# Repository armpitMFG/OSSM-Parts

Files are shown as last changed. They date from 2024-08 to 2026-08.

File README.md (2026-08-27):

# OSSM-Parts

### Summary 
- Parts designed/remixed for improving the OSSM experience
- Model assets (motors, PCBs, etc) to assist designing or rendering 
- Select OSSM Default parts for easier locating

### Print+Hardware Kits available on my Etsy - [https://armpitMFG.etsy.com](https://armpitMFG.etsy.com)

## Licensing

Open-source hardware under the
**[CERN Open Hardware Licence Version 2 - Strongly Reciprocal](LICENSE)**
(`CERN-OHL-S-2.0`), the same licence as the
[OSSM project](https://github.com/KinkyMakers/OSSM-hardware).

Some parts are derived from OSSM project source and carry both armpitMFG's and
the OSSM project's copyright. Some items are third-party work not covered by
this licence, notably `Model Assets` and `OSSM Tools/just_b Wrench`.

Per-part copyright and provenance: [NOTICE.md](NOTICE.md).

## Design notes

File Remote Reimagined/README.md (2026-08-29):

# OSSM Remote Reimagined
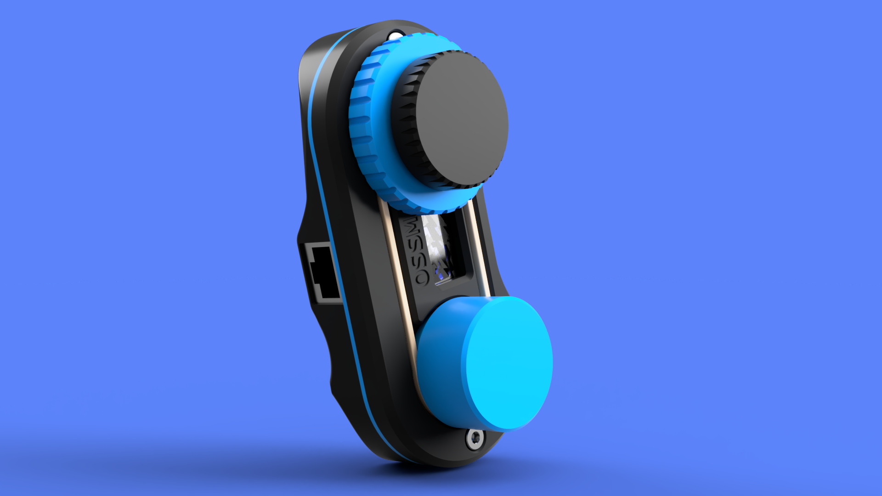
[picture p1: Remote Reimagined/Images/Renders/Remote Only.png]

360 Video (SFW)

## Summary    
Reimagines the OSSM Remote in single-handed form factor allowing control of Speed and Depth knobs (and click) with just one thumb.  
To be used in the right hand.

"Fail-safe" by still allowing traditional use of both knobs.

Print+Part kits: https://armpitmfg.etsy.com/listing/4295260669

### [Print Files](Files/)  

### [Demonstration Video (SFW)](https://www.youtube.com/watch?v=5V_SXpUnVo4) 

### Bill Of Materials
    2x M4-10mm
    ~80mm x ~4mm rubber band

### Notes:
 - Double check ***ALL*** support remnants are cleaned off the screen frame portion of the Board Interface before tightening down
     - Use caution/common-sense when placing the "Board Interface" on, if it feels like it's touching the screen component don't force it.  
Please message me and I will add additional clearance, I'm unsure the clearance needed to cover variance in boards but wanted to keep it tight-ish
 - I found that putting a single twist in the rubberband improves grip between the knobs.
 - There is room for improvement in filament usage and ergonomics for the Bottom, feel free to contribute designs!

### Updates:
  - 01.22.2025 - Added V1.1 Board Interface that gives more space. Untested print. [Images/V1.1.png](Images/V1.1.png)
  - 09.09.2024 - Increase pulley height by 1mm to increase reliability
  - 09.08.2024 - Add **Accent Stripe** file
  - 09.07.2024 - v1 released

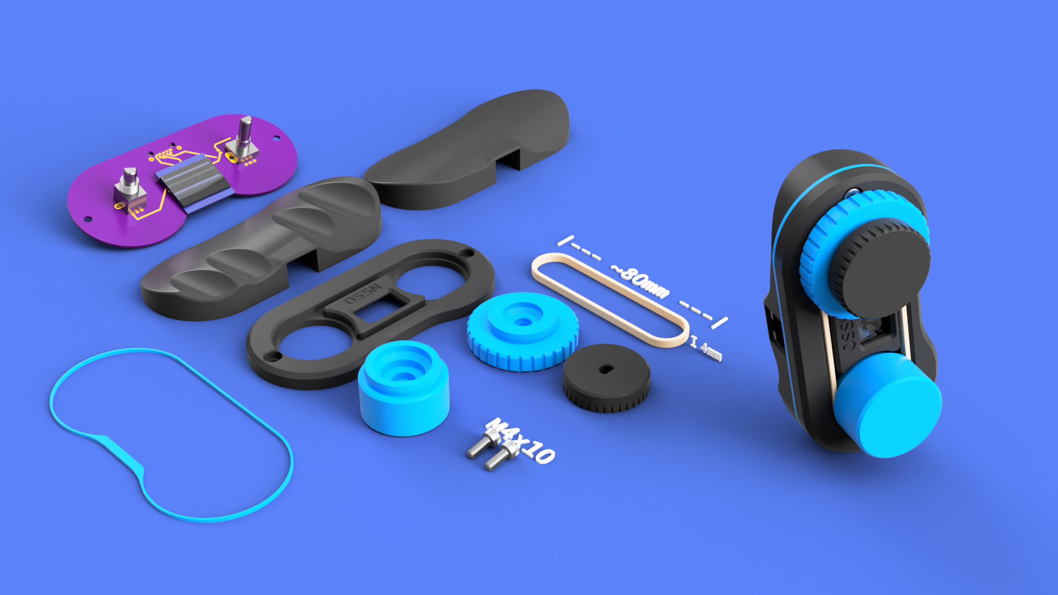
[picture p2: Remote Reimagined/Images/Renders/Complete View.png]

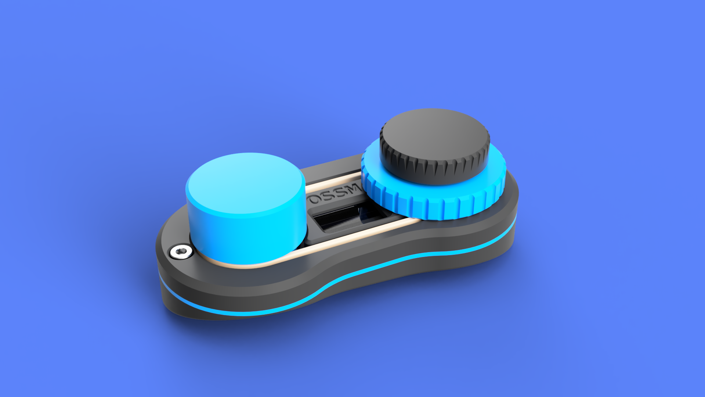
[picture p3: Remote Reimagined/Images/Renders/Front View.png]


## Printing:
  - 0.2mm layer height
  - Standard strength (5 wall) profile
  - 15% gyroid or crosshatch infill

Supports required for:
  - OSSM - Remote Reimagined - Board Interface.stl
  - OSSM - Remote Reimagined - Bottom (any).stl

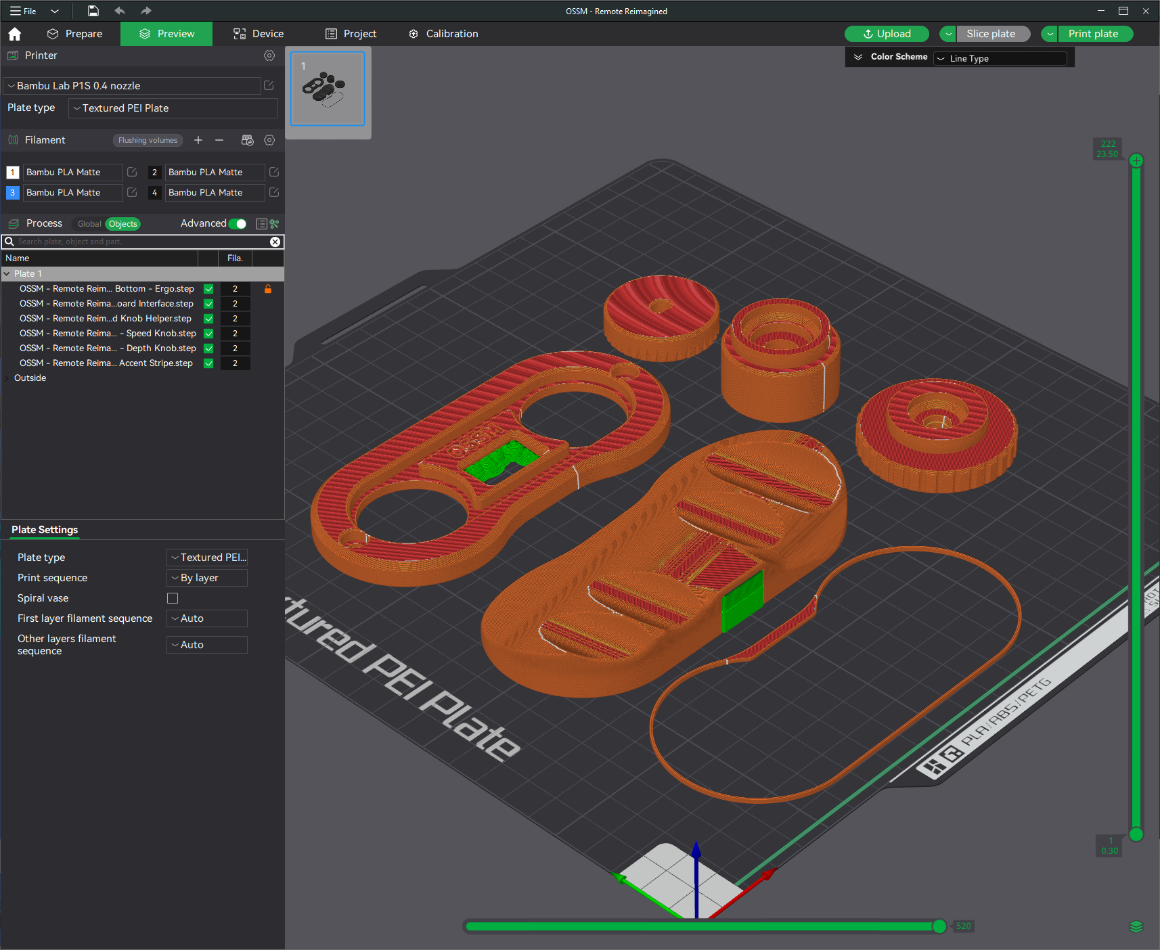
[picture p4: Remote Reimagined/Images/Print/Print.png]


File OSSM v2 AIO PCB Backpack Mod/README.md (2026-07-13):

# OSSM v2 All In One PCB Backpack Mod

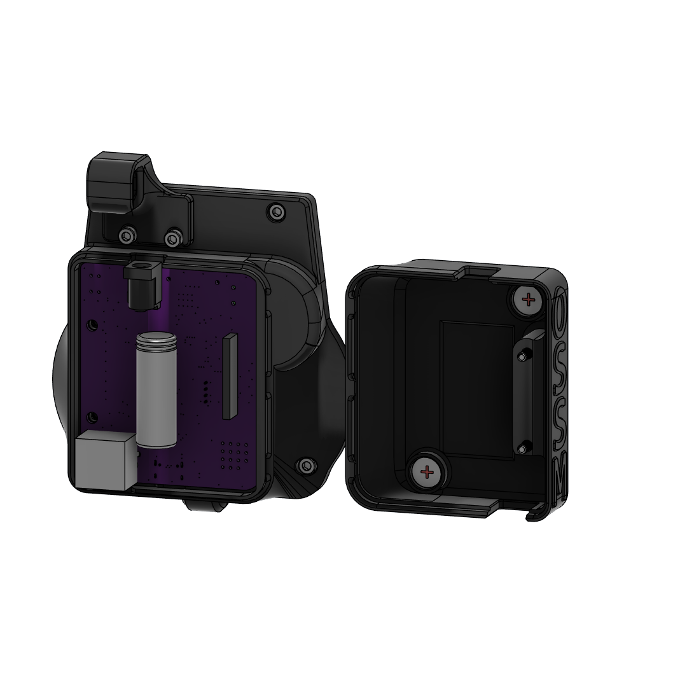
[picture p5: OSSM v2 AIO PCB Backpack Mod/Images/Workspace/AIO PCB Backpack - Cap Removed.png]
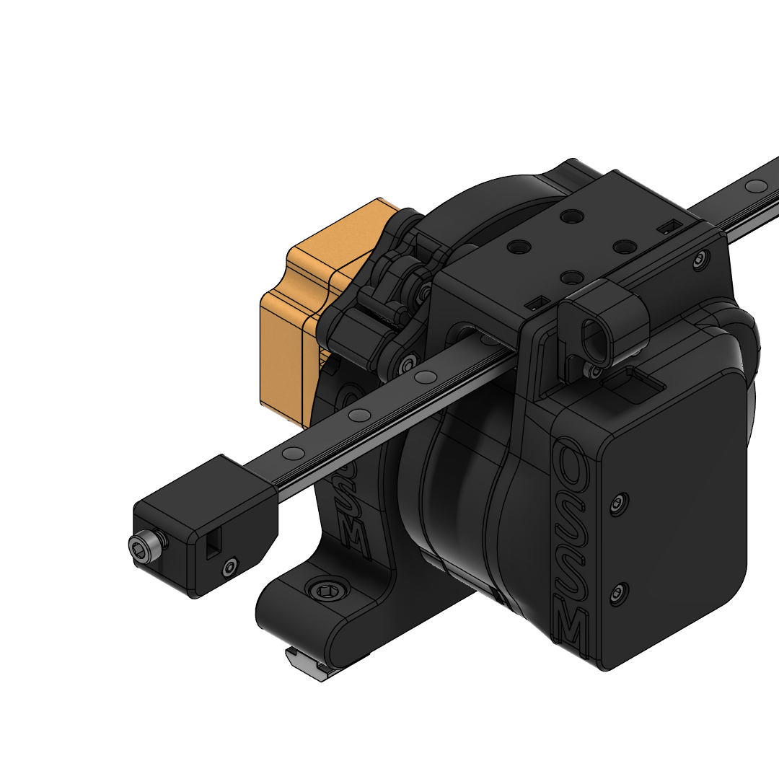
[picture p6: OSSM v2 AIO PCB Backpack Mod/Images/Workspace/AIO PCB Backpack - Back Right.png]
|||
| --- | --- |

## Summary   
This is a mod that converts the default "OSSM - Body - Cover" into a PCB enclosure with cable routing designed to pair up with my other mod - [OSSM Motor Cover](https://github.com/armpitMFG/OSSM-Parts/tree/main/OSSM%20Motor%20Cover) - on 57AIM30 "Gold Motor" setups.  

This OSSM setup utilizes the [PitClamp Mini](https://github.com/KinkyMakers/OSSM-hardware/tree/master/Printed%20Parts/Mounting/PitClamp%20Mini) mounting system.

Interlocking interface helps prevent fluid intrusion.

Print+Part kits: https://armpitmfg.etsy.com/listing/1861883228

### Requires v1.1 PitClamp Mini Motor Ring  

## Capacitor Support
- Supports capacitors up to 18mm diameter, should fit all existing v2.x reference boards

### Motor Support
- 57AIM30
- iHSV57
  - No cover mod for this motor, no passthru ring
  - Use 4pin header for motor signal

## [Print Files](Files/)  
 - All parts are intended to print in the provided file orientation (as seen in slicer preview below)  
   - Auto-orient may position parts incorrectly
 - Variation available for covered RJ45 port (Useful if you have a wireless remote)
 - There may be various design tricks that take advantage of 0.2mm layer height in this default orientation

## Bill Of Materials
  - 2x M3x25 Socket Head Cap Screw
  - 4x M3x12 Socket Head Cap Screw
  - 6x M3 Hex Nut 
    - (4 are from original Cover)
  - (Optional) cable strain relief add-on
    - 2x M3x12
    - 2x M3 Hex Nut
  - (Optional) Magnetic Faceplate
    - 2x 10x2mm Neodymium magnets

Print+Part kit: https://armpitmfg.etsy.com/listing/1861883228

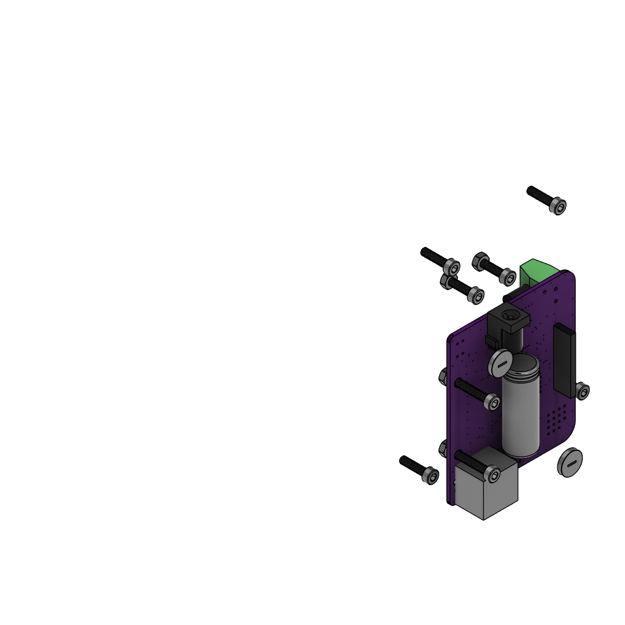
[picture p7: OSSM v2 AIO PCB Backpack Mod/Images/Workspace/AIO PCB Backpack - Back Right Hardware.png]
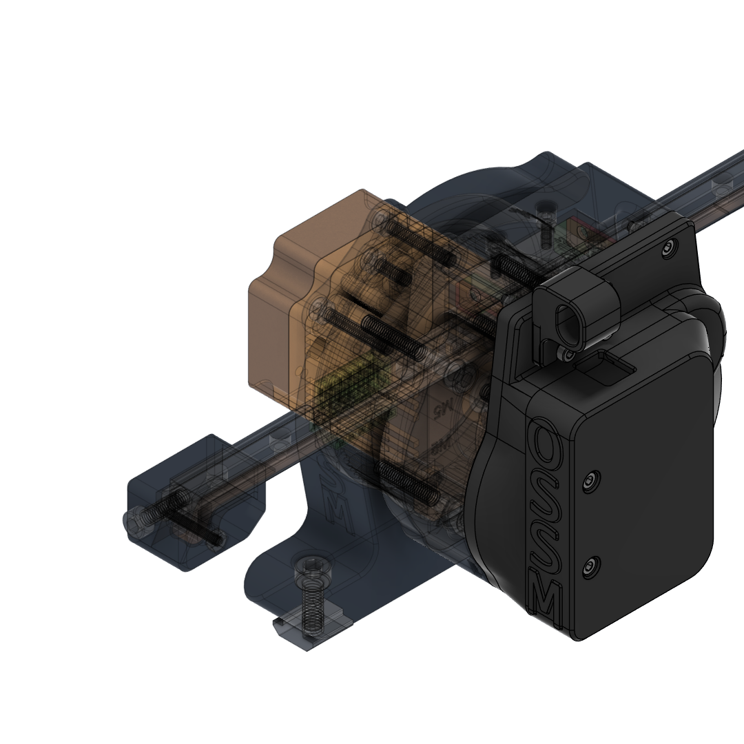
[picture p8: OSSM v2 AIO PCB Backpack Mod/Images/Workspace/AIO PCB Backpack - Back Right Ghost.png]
| | |
| --- | --- | --- |

## Assembly

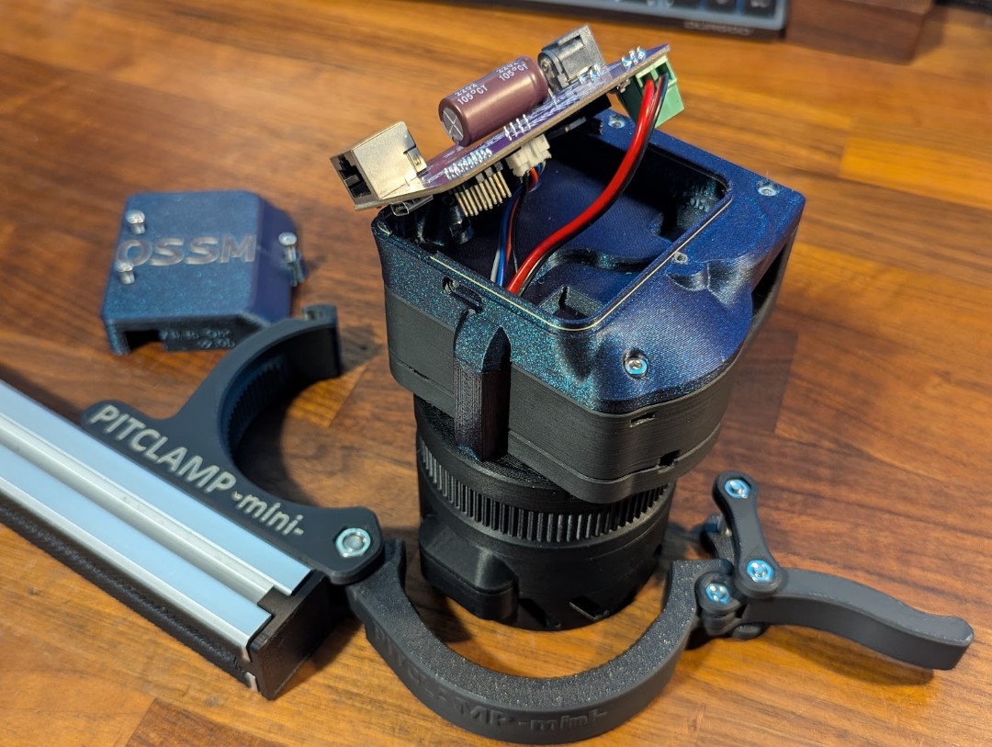
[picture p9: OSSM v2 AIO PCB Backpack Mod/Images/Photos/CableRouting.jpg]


0. If you plan to use a Motor Cover, follow that install procedure first.  
   If you plan to use magnetic faceplates, press-fit magnets into "Backpack - Cap".
1. Install the 2x m3x12 + nuts with cable strain relief (or without a relief installed if you plan to use one in the future).
2. Remove "OSSM - Body - Cover" from the OSSM if installed, ensure 4x M3 nuts are installed in "OSSM - Body (Middle and Bottom)" slots.  
3. Route wires through "Backpack - Base". This is easiest if you are able to feed individual wires through, but the hole should accommodate the 4 pin plug if it is inserted before the power leads.  
4. Set the Base in place on "OSSM - Body - Middle" and secure it loosely with 4x M3x12 screws.  
5. Insert 2x M3 nuts into Base inner slots past the notch. Be careful to keep these aligned in future steps.  
6. Attach 4 pin motor signal cable and power leads to the OSSM Reference Board.  
7. Set the board in place, temporarily, guiding wires into the recessed areas and removing slack when necessary.
8. Insert "Backpack - Wire Cover" into place over the wire between "Backpack - Base" and "Ring v1.1". The smaller ridge fits into the Ring passthru hole.  
9.  Lean the OSSM Reference Board out of the way and finish tightening the two lower Base screws while securing the Wire Cover in place. (Hold nuts in place with a small tool if they spin in place)  
10. Finish tightening the two upper Base screws  
11. Set "Backpack - Cap" in place, sliding the right side into the grooves, and secure using 2x M3x25, ensuring the recessed nuts are tightened against and did not slide out of place.

## Updates
  - 08.20.2025 - Shortened default wire cover (Keeping +1mm version as an option)
  - 07.16.2025 - v2.3c Base Release (Widened USB port)
  - 05.13.2025 - v2.3b Base Release (M3 nut slot tolerance increased by 0.2mm)
  - 04.13.2025 - v2.3 Release (Bottom M3 nut slots improved for assembly and printability, cable passthru widened, retention ridges added for 10x2 magnets)
  - 03.08.2025 - v2.2 Release (Bottom and Cap right side connection changed for reduced BOM and more reliable assembly)
  - 01.22.2025 - Corrected docs M3 bolt spec. Limited to 20mm.
  - 12.21.2024 - v2.01 Cap update (Universal size, easier printing, magnet inserts)
  - 12.19.2024 - v2.0 Release

## Printing

**Recommend using preconfigured 3mf file - [OSSM v2 AIO PCB Backpack Mod.3mf](Files/Preconfigured%203mf%20Files/)**  
Just pick the Backpack Cap you want to keep and remove the other.

    0.2mm layer height
    Standard strength (5 wall) profile
    20% crosshatch or gyroid infill
    No supports required

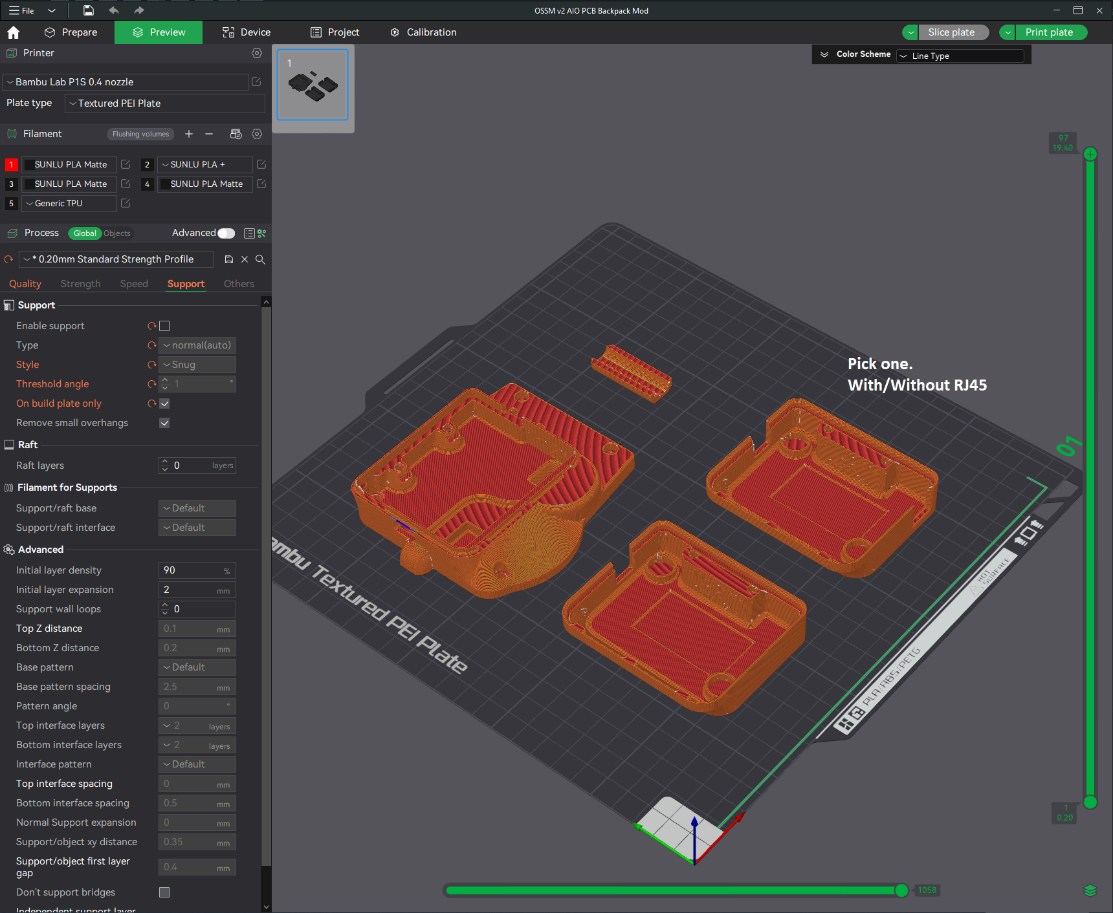
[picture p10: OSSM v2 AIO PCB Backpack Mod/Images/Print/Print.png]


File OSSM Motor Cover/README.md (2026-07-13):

# PitClamp Mini Motor Cover
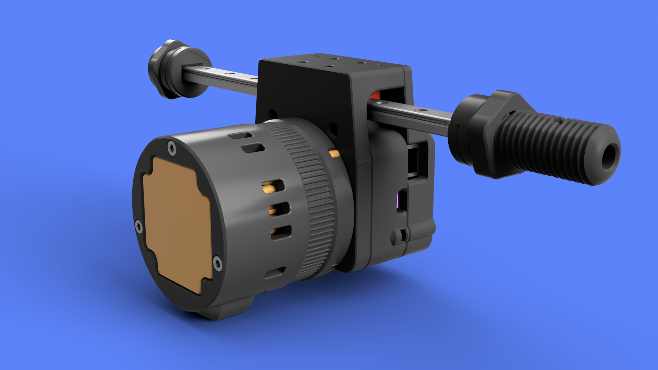
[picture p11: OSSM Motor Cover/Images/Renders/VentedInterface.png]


## Summary    
This is a motor cover for OSSM setups that utilize the [PitClamp Mini](https://github.com/armpitMFG/PitClamp-Mini) mounting system combined with the [OSSM v2.x Board AIO Motor Head Mod](https://github.com/armpitMFG/OSSM-Parts/tree/main/OSSM%20v2.x%20AIO%20Motor%20Head%20Mod)  

Interlocking interface helps prevent fluid intrusion.

The cover parts come in different levels of ventilation or sealed.  
Choose what will work best for your use; Motor Cover pieces are interchangable.  

Print+Part kits: https://armpitmfg.etsy.com/listing/1866948824

### Requires v1.1 PitClamp Mini Motor Ring  
Compatible with all PitClamp Mini bases, just needs a new motor ring to support the cover mounting.

### Motor Support
- 57AIM30
- 42AIM30 (Future)
- 42AIM15 (Future, maybe..)  

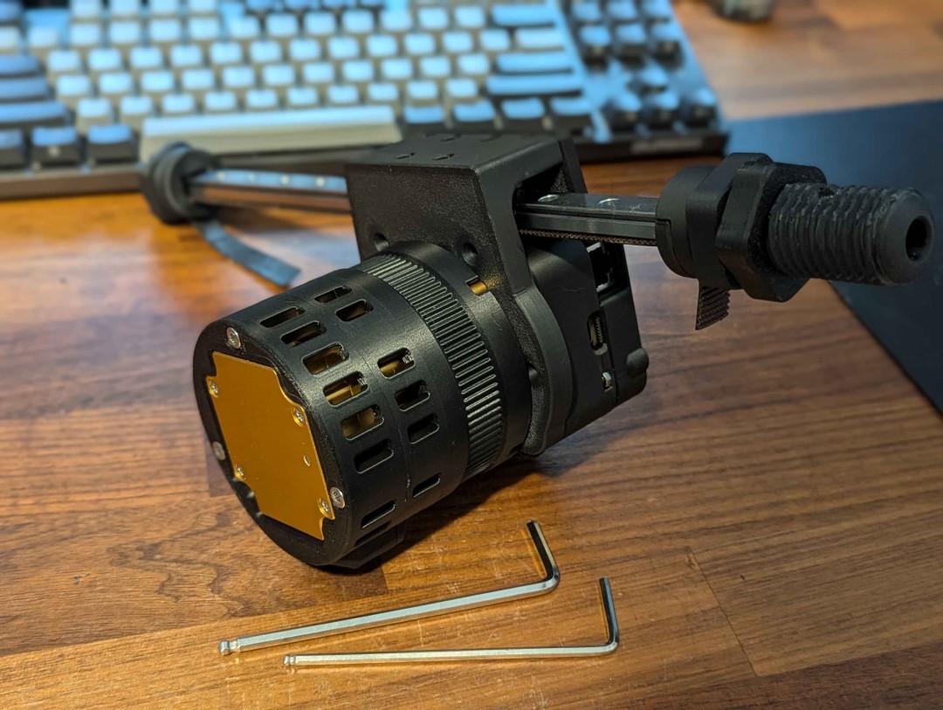
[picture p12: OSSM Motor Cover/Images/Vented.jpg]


## [Print Files](Files/)  
All parts are intended to print in the provided file orientation (as pictured below)  
There are various design tricks that take advantage of 0.2mm layer height in this default orientation.

## Bill Of Materials
  - 3x M4x25 Socket Head Cap Screw
  - 3x N4 Nut
  - [4x M5 Hex Coupling Nuts 20mm](https://www.amazon.com/uxcell-0-8-Pitch-Length-Stainless-Coupling/dp/B07JPYF4DC/) (Just for reference, likely better prices around)
  - 4x M5x10 Socket Head Cap Screw
  - 4x M5x35 Socket Head Cap Screw 
    - (It's possible to use 2x M5x30 + 2x M5x35) 
    - [OR 4x M5x30, though not recommended]

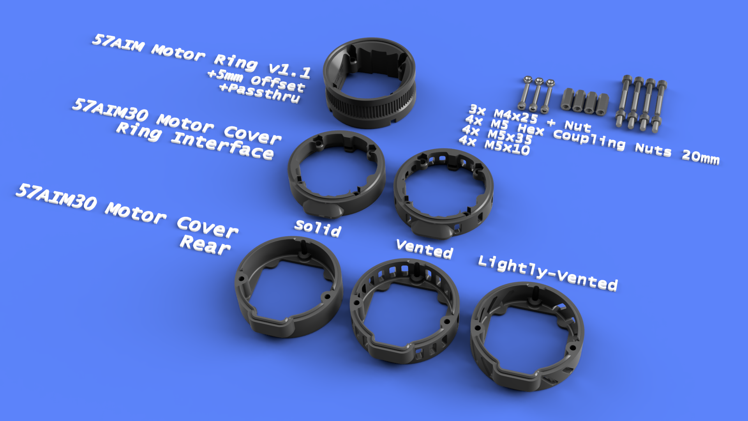
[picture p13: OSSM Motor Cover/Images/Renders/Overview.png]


## Assembly

Route the cable through Ring v1.1 Passthru hole, slide motor into place  
Insert 4x M5 Hex Coupling Nuts 20mm into Ring v1.1 nut slots. ***MUST BE 20mm***  
Attach motor head ([OSSM v2.x Board AIO Motor Head Mod](https://github.com/armpitMFG/OSSM-Parts/tree/main/OSSM%20v2.x%20AIO%20Motor%20Head%20Mod) recommended) using 4x M5x35  
Insert 3x M4 nuts into Ring Interface nut slots  
Slide Ring Interface into position against Ring v1.1 with cable routed  
Secure Ring Interface using 4x M5x10 into Hex Coupling Nuts  
Plug motor cable into motor  
Slide Rear into position against Ring Interface  
Secure Rear using 3x M4x25  

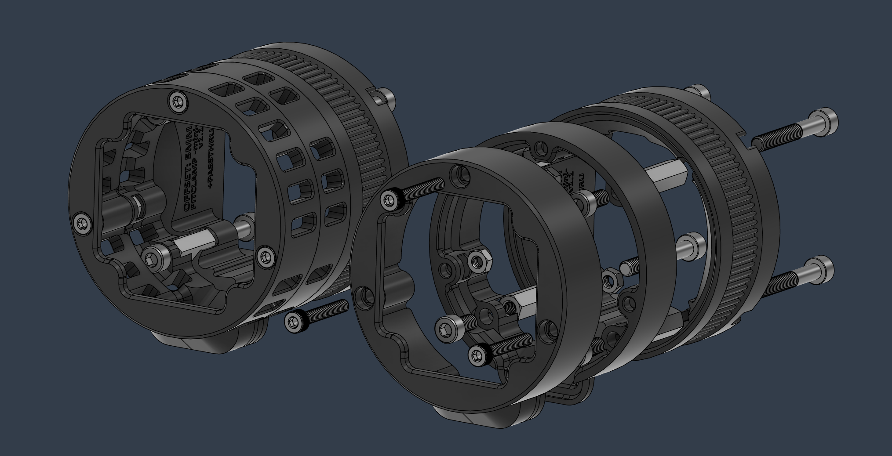
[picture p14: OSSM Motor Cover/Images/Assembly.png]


## Updates
  - 09.30.2024 - v1.0 Release

## Printing

**Recommend using preconfigured 3mf file - [PitClamp Mini - Motor Cover- 57AIM30.3mf](Files/Preconfigured%203mf%20Files/)** just remove the parts you don't need.

    0.2mm layer height
    Standard strength (5 wall) profile
    20% gyroid or crosshatch infill
    Tree/organic Supports ~10deg overhang setting
      "Support critical regions only"
  
Supports required for:
  - PitClamp Mini - Ring v1.1 - 57AIM - 5mm Offset +Passthru
  - PitClamp Mini - Motor Cover - 57AIM30 - Rear (any)

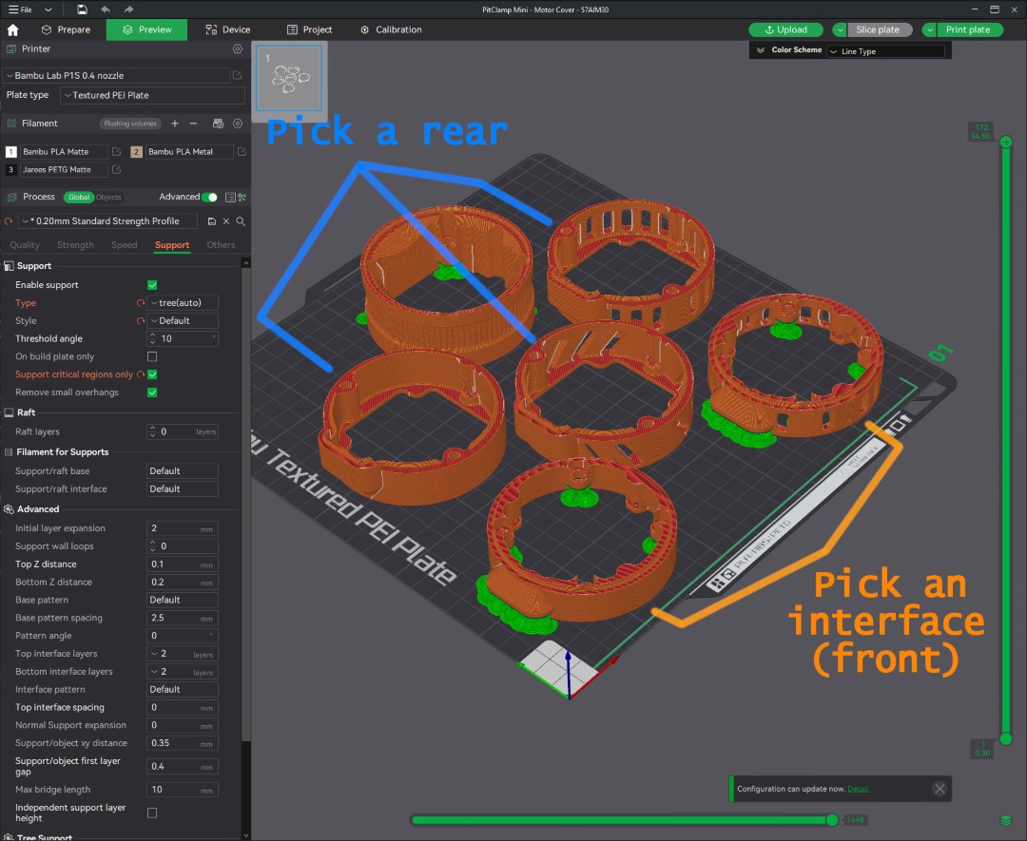
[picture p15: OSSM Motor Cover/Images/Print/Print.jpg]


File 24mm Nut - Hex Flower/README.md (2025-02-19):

# 24mm Nut - Hex Flower - Single/Double Threaded
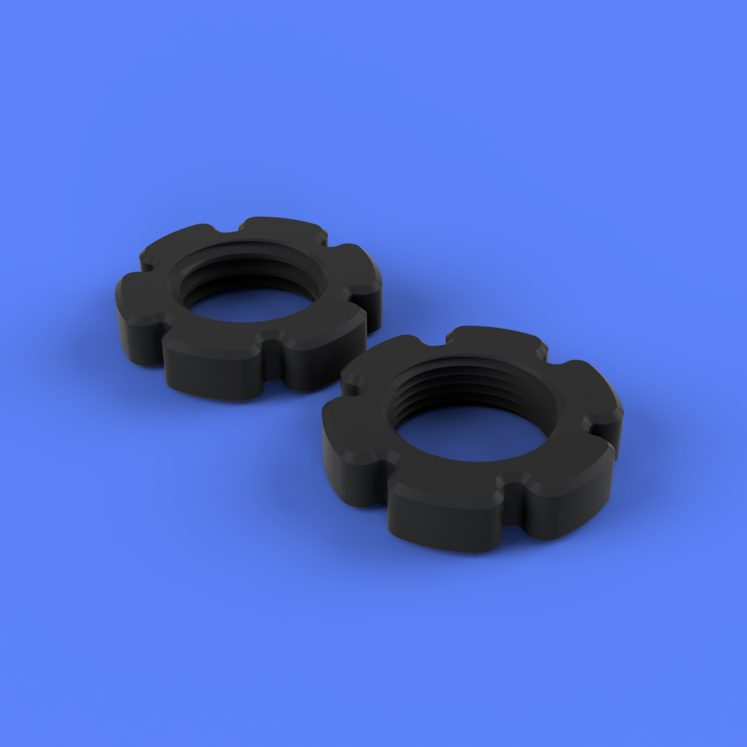
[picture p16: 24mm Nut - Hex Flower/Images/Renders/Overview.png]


## Summary
* Tapered thread entry for easier initial threading
* 40mm outer diameter with smooth "flower petal" edges
  * Petal shape design causes wall overlap when printing with 5+ walls, 0.4 nozzle, increasing part strength
  * Petal shape gives finger grip points and allows for wrench use
* [Experimental] Double-threaded version has 180 degree offset thread for easier initial threading (Doubles the chance of threads catching)
  
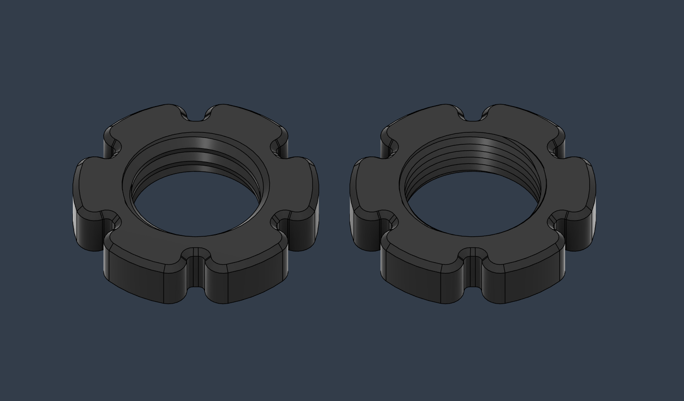
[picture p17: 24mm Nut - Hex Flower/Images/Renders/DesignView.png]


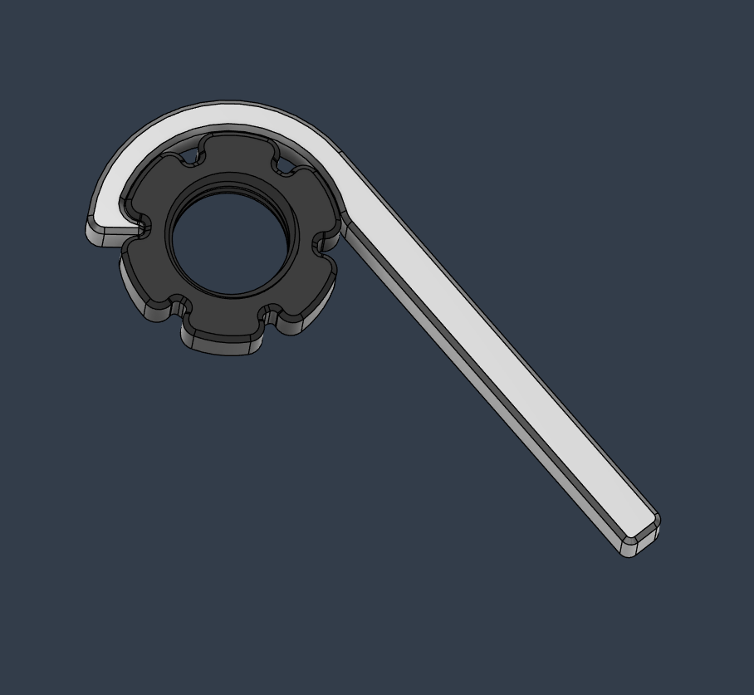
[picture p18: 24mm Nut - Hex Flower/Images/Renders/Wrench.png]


## [Print Files](Files/)  

## Printing

    0.2mm layer height
    Standard strength (5 wall) profile
    20% gyroid or crosshatch infill

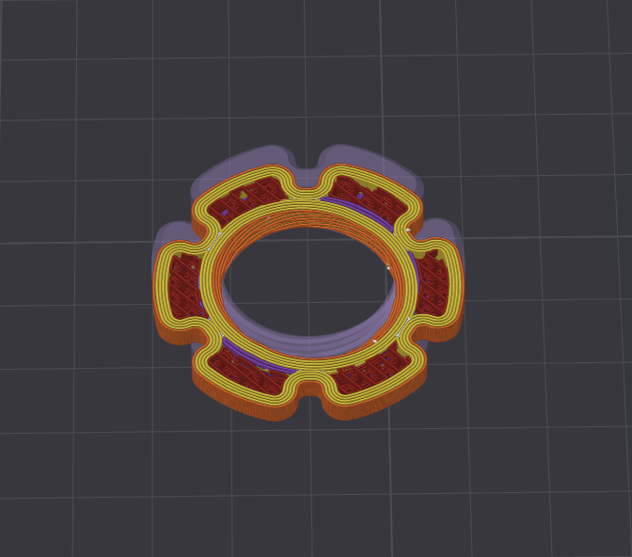
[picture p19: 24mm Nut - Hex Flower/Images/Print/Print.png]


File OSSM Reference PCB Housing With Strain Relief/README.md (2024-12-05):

## OSSM Reference PCB Housing - Remix w/ Strain Relief

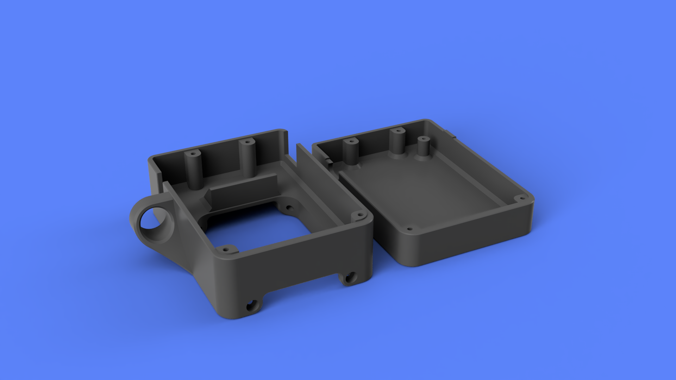
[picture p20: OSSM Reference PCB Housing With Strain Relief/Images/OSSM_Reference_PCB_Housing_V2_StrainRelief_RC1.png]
OSSM Reference PCB Housing - Remix w/ Strain Relief
  
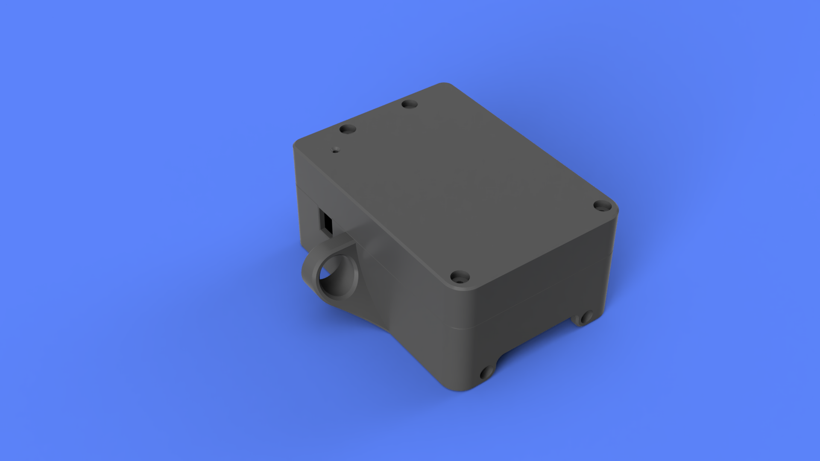
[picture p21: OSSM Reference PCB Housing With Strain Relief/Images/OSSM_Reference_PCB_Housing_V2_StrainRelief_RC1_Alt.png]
OSSM Reference PCB Housing - Remix w/ Strain Relief
  

**Summary**  
Adds a strain relief for the power plug with a 12.5mm inner diameter (a little larger than typical barrel plug)  
Reduces size and number of holes on the top for a more minimal look and reduced LED brightness  
Widened footprint by 2mm total to add more tolerance for board fit

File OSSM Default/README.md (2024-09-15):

# OSSM Default

### Summary
This is where source files can be found for select OSSM Default parts.  
Fusion and STEP where possible.

## Requests

Need a specific file? Submit a PR against this readme.  

Have a file someone has requested? Submit a PR.

    Current Requests:
    N/A

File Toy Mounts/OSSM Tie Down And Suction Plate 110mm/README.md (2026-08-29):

# Tie Down And Suction Plate 110mm
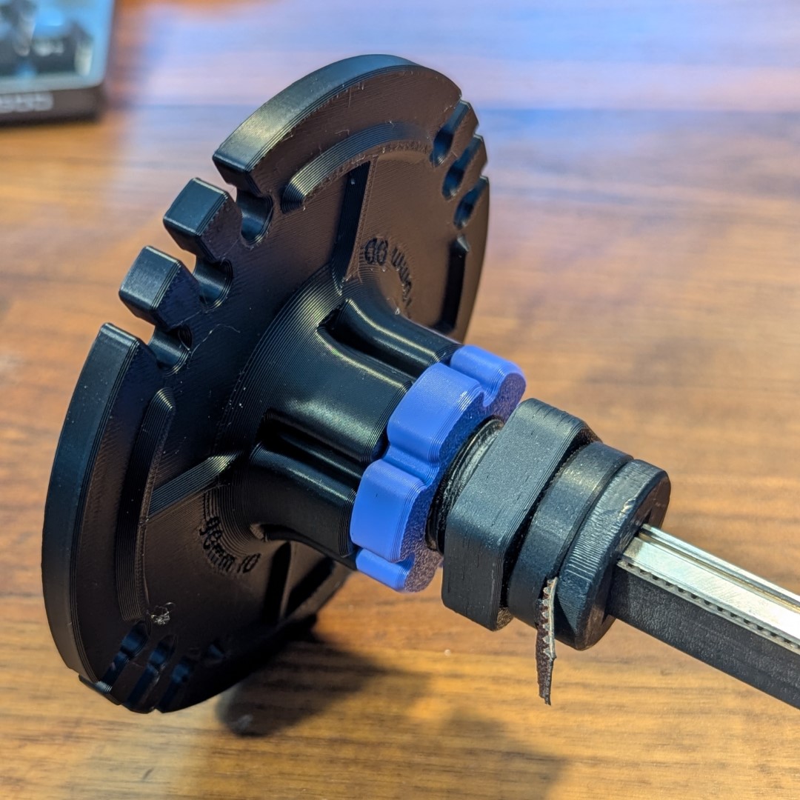
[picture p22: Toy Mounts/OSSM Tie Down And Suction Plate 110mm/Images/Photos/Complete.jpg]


## Summary   
This is a tiedown plate with a pattern of 6mm mounting holes for securing latex tubing or other rope with knotted ends routed to the rear and a robust 24mm thread design with tapered entry.  

Compatibility with suction bases up to 90mm diameter  
Overall plate size of 110mm diameter

Print kits: https://armpitmfg.etsy.com/listing/1900397333

## [Print Files](Files/)  
 - Intended to print in the provided file orientation (as seen in slicer preview below)  

## Bill Of Materials
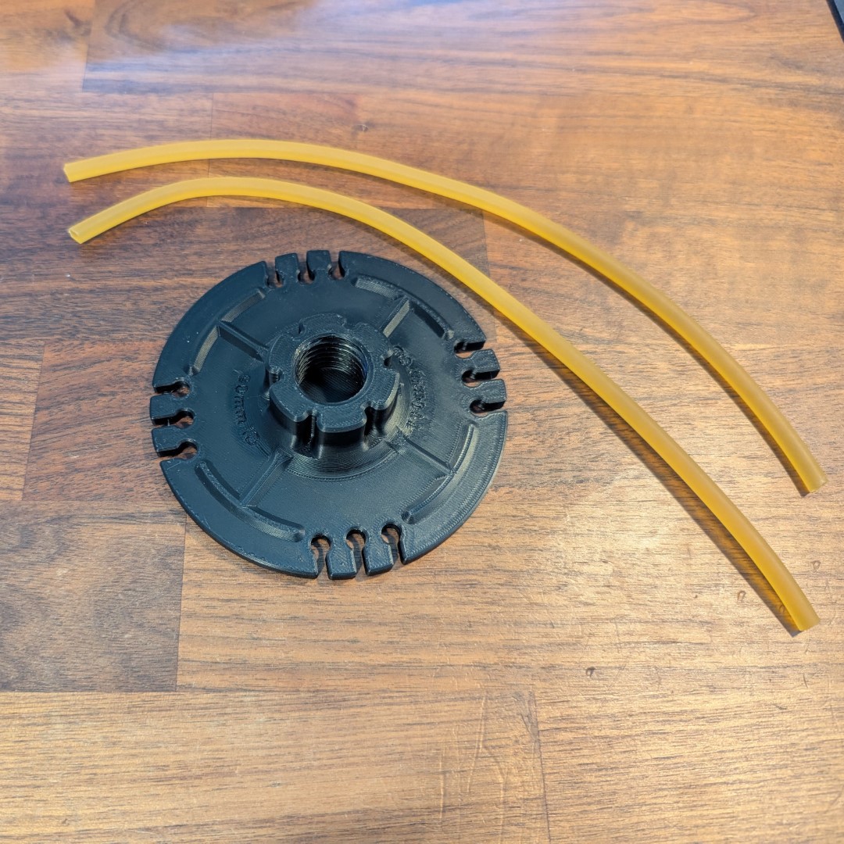
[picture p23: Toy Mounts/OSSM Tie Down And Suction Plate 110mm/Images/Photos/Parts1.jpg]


  - 6mm/7mm (1/4") solid latex tubing 
    - 2x lengths cut to ~12"

## Assembly

1. Tie an "infinity" knot at all four ends of the latex tubing
2. Route tubing through holes and around toy to secure to base  

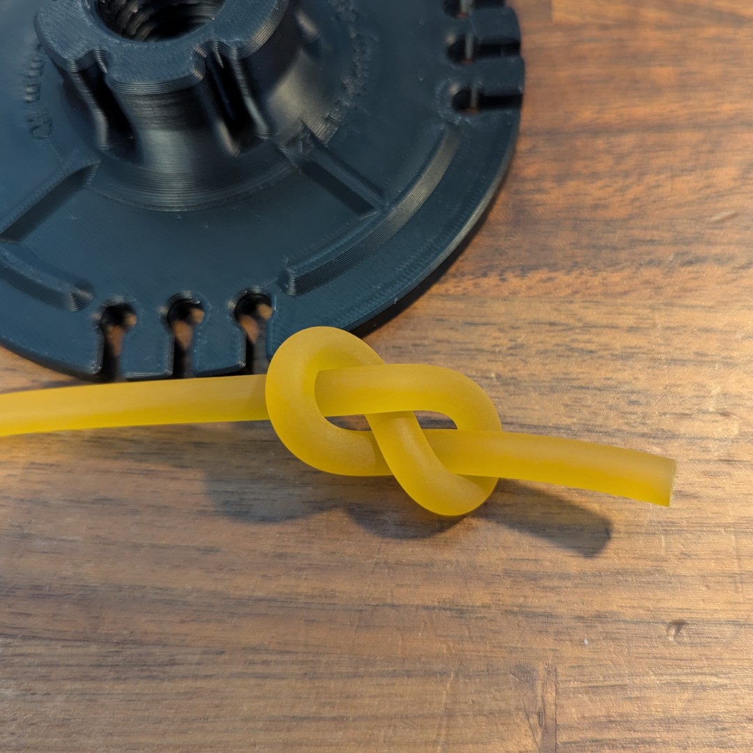
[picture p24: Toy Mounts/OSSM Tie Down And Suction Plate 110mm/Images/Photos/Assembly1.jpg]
    
    

## Printing
    0.2mm layer height
    Standard strength (5 wall) profile
    15% crosshatch or gyroid infill
    10 top shell layers
    10 bottom shell layers
  
No supports required.

A smooth finish for suction cup can be achieved by using a smooth PEI plate  
**Smooth PEI plate preconfigured 3mf file - [OSSM Tie Down And Suction Plate 110mm (Smooth PEI).3mf](Files/Preconfigured%203mf%20Files/)**  



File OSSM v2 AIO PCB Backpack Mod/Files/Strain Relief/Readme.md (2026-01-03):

# Strain Relief 


Some form of strain relief is recommended; having the control board closer to the motor raises the potential for tugs or strains on the power input.

*See STEP subdirectory for a template with bolt patterns*

## Assembly Advice
Even if you do not have a strain relief designed or that fits your need, consider inserting the nuts and two screw during assembly to make adding your strain relief easier later.

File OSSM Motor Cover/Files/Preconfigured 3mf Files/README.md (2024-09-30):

### Note  
This 3mf is for Bambu slicer until someone commits a version for another slicer.  

I have learned that the support and infill settings will not import properly to other slicers.  

Use these settings if you are using another slicer:  

    0.2mm layer height
    Standard strength (5 wall) profile
    20% gyroid or crosshatch infill
    Tree/organic Supports ~10deg overhang setting
    "Support critical regions only"



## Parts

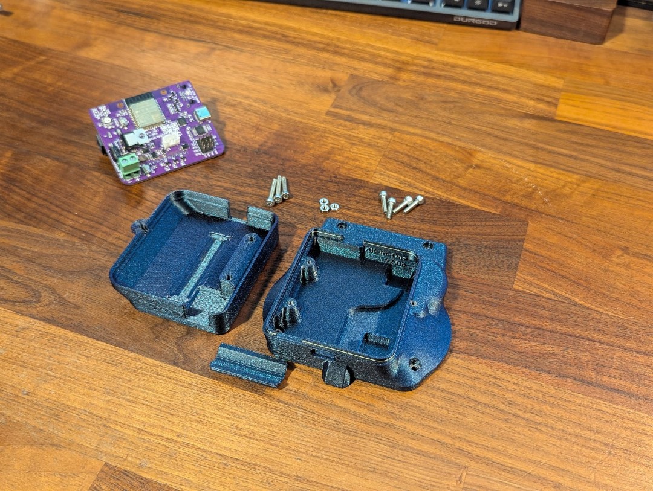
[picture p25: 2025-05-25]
OSSM v2 AIO PCB Backpack Mod/Images/Photos/Parts1.jpg

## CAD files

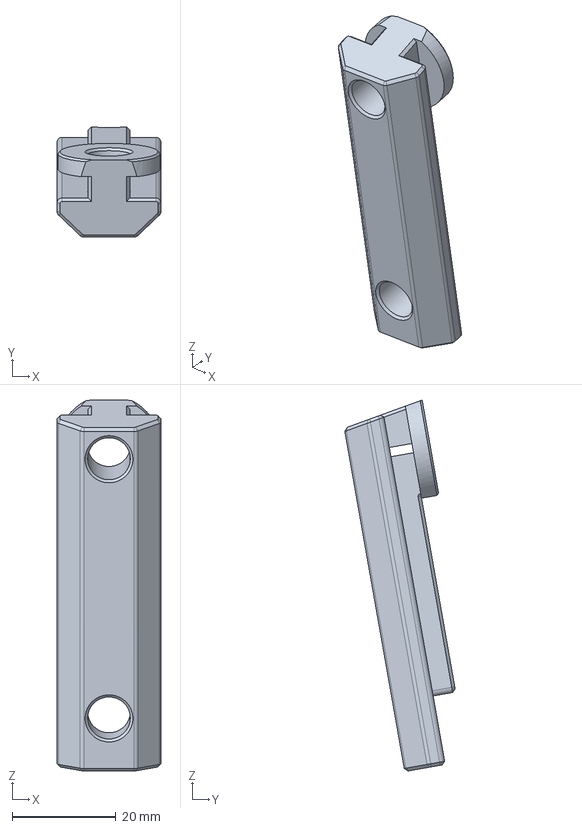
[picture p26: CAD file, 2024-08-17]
Metal Hinge Printed Files/STEP/Hinge 40-4040CL.step
20.0 x 21.2 x 71.4 mm

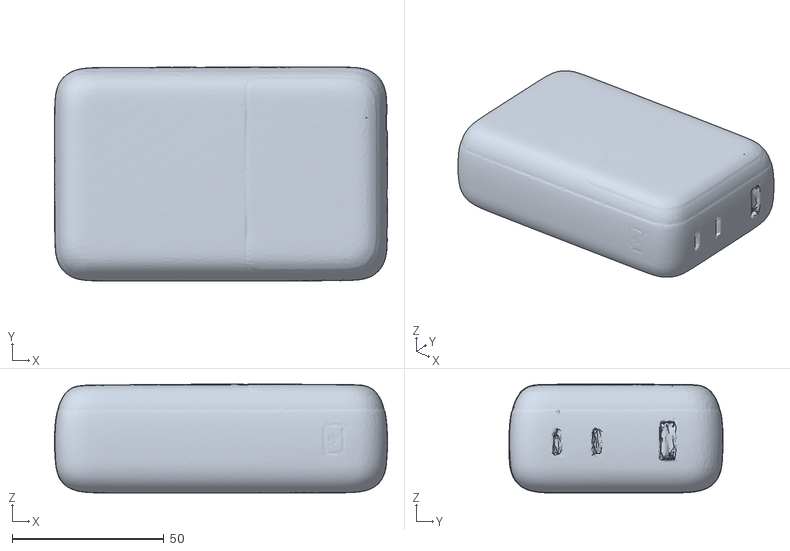
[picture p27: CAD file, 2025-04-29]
Model Assets/Misc/P63E1.STL
109.7 x 70.6 x 35.9

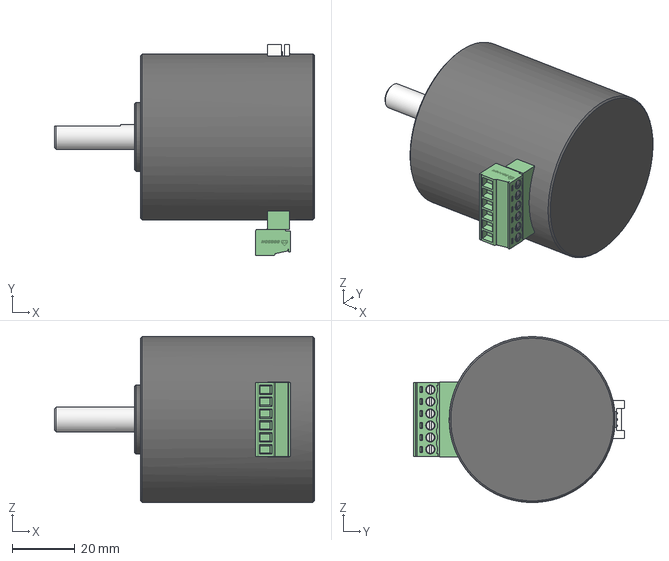
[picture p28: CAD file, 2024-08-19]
Model Assets/Motors/42AIM15.step
83.0 x 67.4 x 53.0 mm

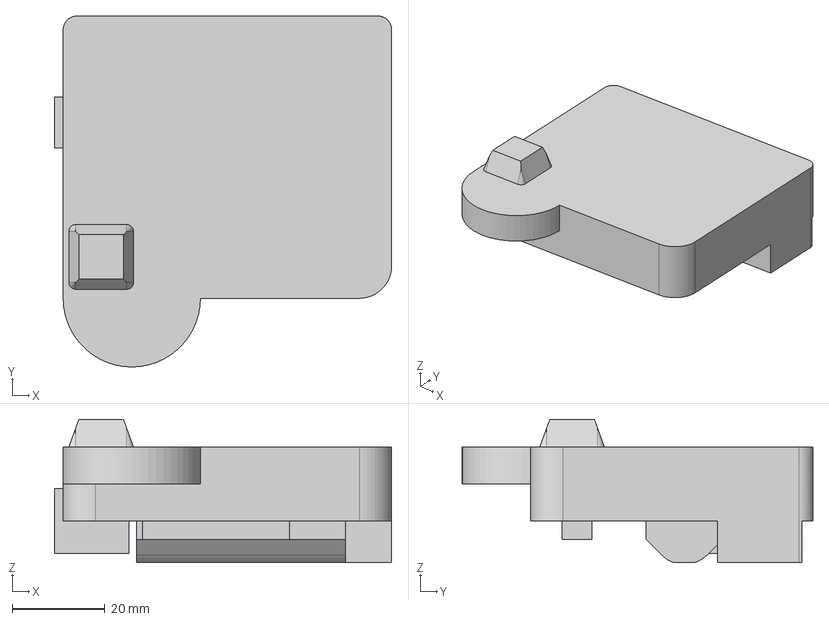
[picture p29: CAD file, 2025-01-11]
Model Assets/Reference Board/OSSM Reference Board v2.x Cutout Template.step
72.9 x 75.8 x 31.0 mm

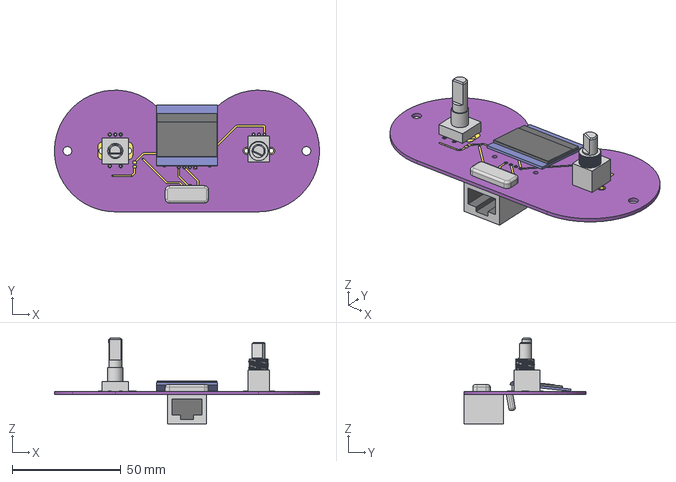
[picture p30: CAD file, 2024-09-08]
Model Assets/Remote Board/OSSM Remote PCB.step
122.0 x 56.0 x 39.4 mm

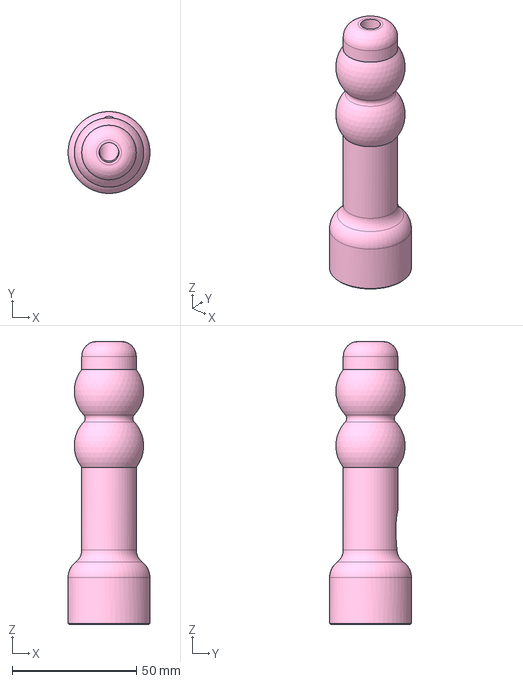
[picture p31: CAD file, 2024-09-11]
OSSM Default/End Effectors/Double Double To The Moon 24mm/Double Double To The Moon 24mm.step
33.0 x 33.0 x 114.0 mm

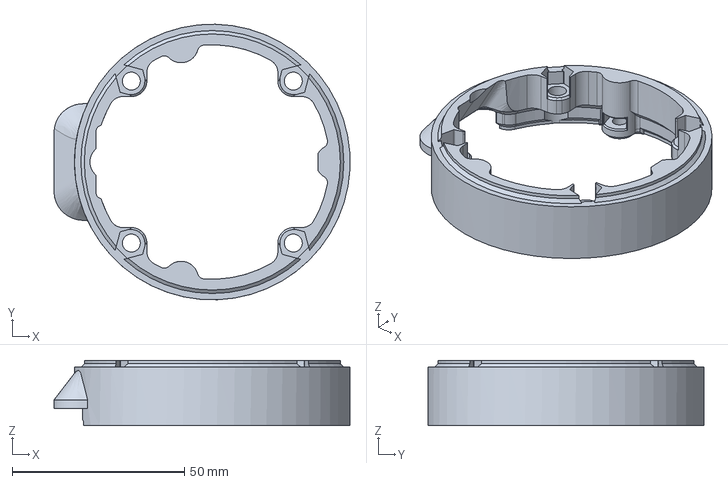
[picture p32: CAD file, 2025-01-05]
OSSM Motor Cover/Files/STEP/PitClamp Mini - Motor Cover - 57AIM30 - Ring Interface - Sealed.step
85.9 x 80.0 x 19.0 mm

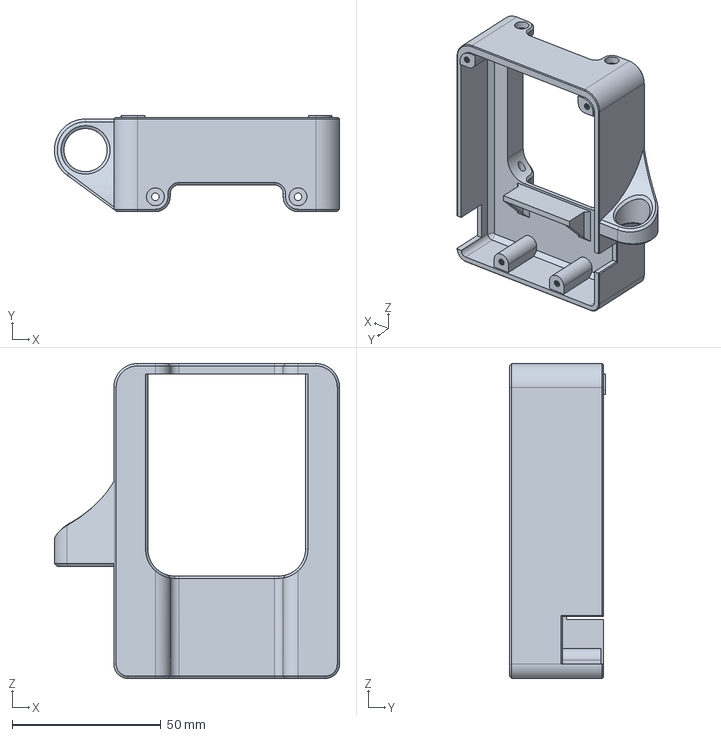
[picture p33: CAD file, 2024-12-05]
OSSM Reference PCB Housing With Strain Relief/Release Files/STEP/OSSM_Reference_PCB_Housing_V2_StrainRelief_Top_Reinforced_Widened_RC1.step
96.0 x 32.4 x 106.0 mm

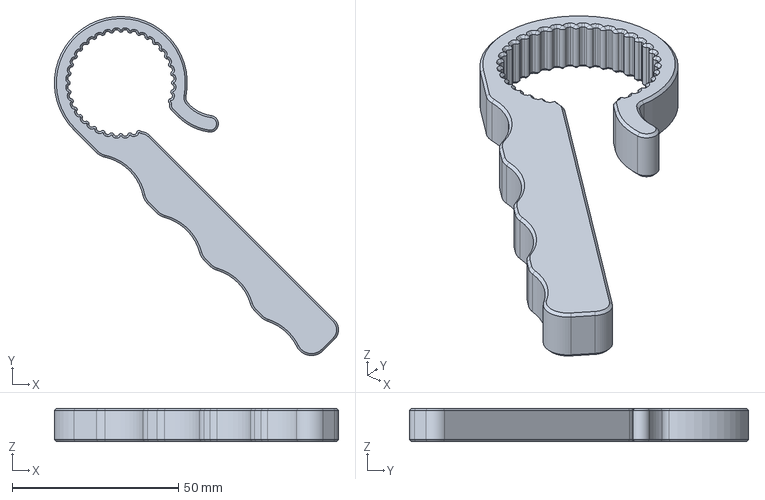
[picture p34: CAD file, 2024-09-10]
OSSM Tools/just_b Wrench/Files/STEP/just_b Wrench.step
85.5 x 102.0 x 10.0 mm

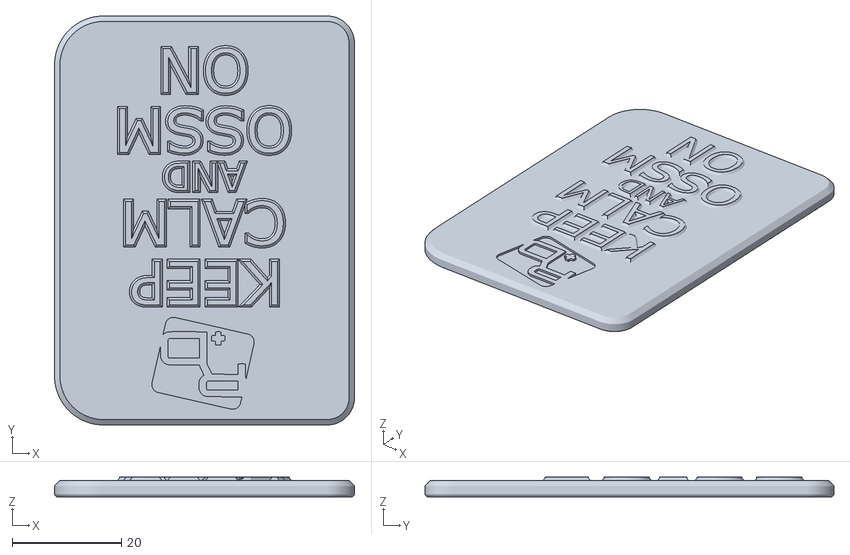
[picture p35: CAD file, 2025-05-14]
OSSM v2 AIO PCB Backpack Mod/Files/Faceplates/Keep Calm.stl
55.0 x 75.0 x 3.60

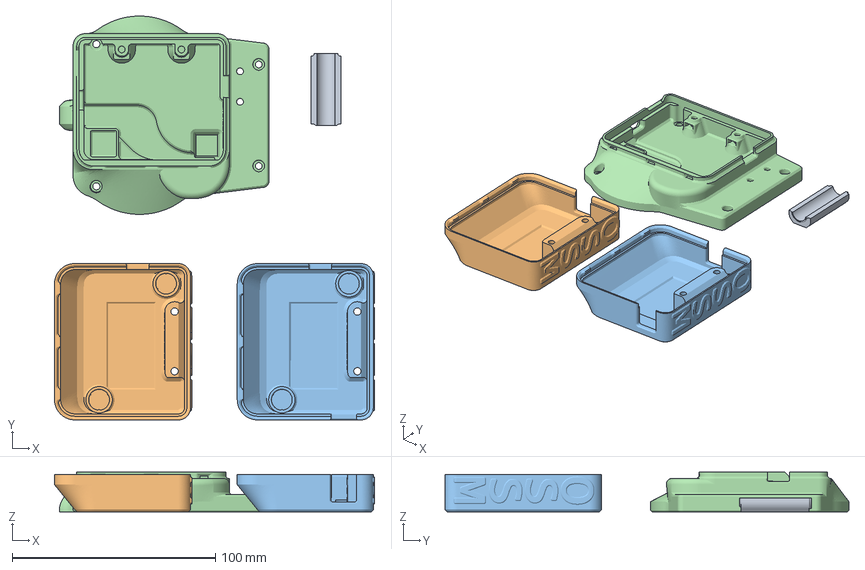
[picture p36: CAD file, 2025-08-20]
OSSM v2 AIO PCB Backpack Mod/Files/Preconfigured 3mf Files/[BBL_A1] OSSM v2 AIO PCB Backpack Mod.3mf
157.6 x 198.9 x 19.5 mm
Wire Cover
OSSM Mods - AIO PCB Backpack - Cap (No RJ45).stp
OSSM Mods - AIO PCB Backpack - Cap (Default).stp
OSSM Mods - AIO PCB Backpack - Base.step

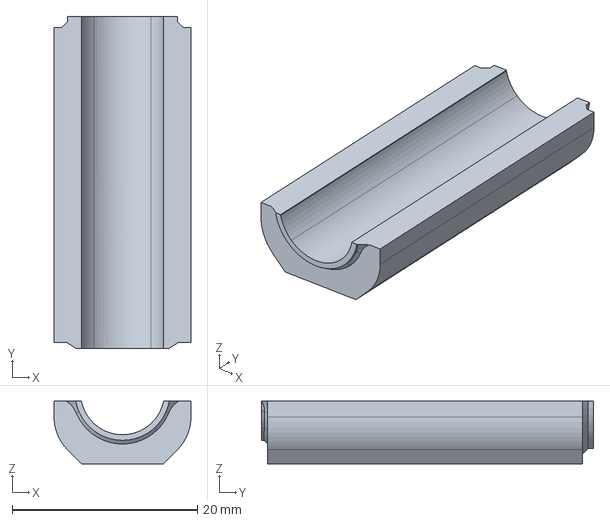
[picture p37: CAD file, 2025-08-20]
OSSM v2 AIO PCB Backpack Mod/Files/STEP/OSSM Mods - AIO PCB Backpack - Wire Cover (+1mm).stp
14.8 x 35.9 x 6.80 mm

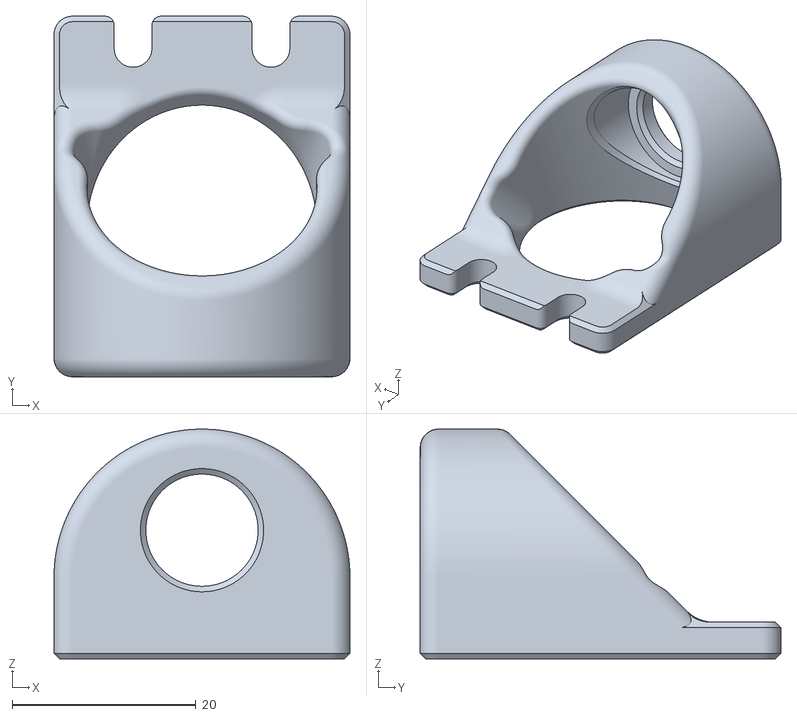
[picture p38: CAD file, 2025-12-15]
OSSM v2 AIO PCB Backpack Mod/Files/Strain Relief/OSSM Mods - AIO PCB Backpack - Strain Relief - Meanwell 36v R7BF-P1J.stl
32.2 x 39.2 x 25.0

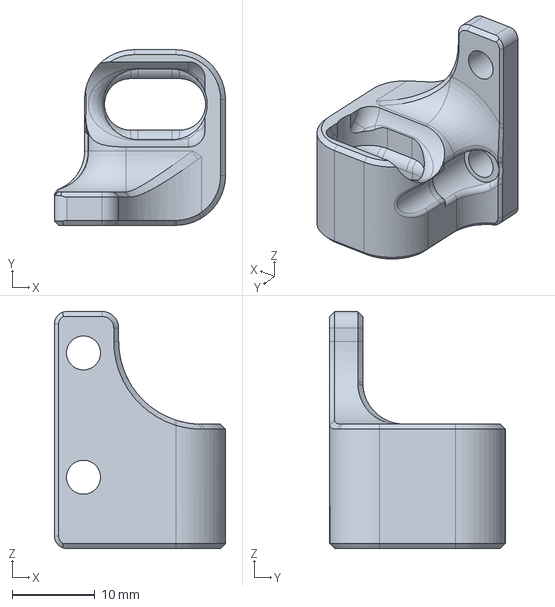
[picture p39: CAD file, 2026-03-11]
OSSM v2 AIO PCB Backpack Mod/Files/Strain Relief/STEP/Strain Relief - USBC 90 Degree - generic.step
20.6 x 21.2 x 28.6 mm

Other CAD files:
Remote Knobs/STEP/Remote Knob - Simple.step
Remote Reimagined/Files/OSSM - Remote Reimagined.3mf
Remote Reimagined/Files/STEP/OSSM - Remote Reimagined - Board Interface V1.1.step
Toy Mounts/OSSM Tie Down And Suction Plate 110mm/Files/Preconfigured 3mf Files/OSSM Tie Down And Suction Plate 110mm (Smooth PEI).3mf
24mm Nut - Hex Flower/Files/24mm Nut - Hex Flower - Double Threaded.stl
24mm Nut - Hex Flower/Files/24mm Nut - Hex Flower - Single Threaded.stl
24mm Nut - Hex Flower/Files/24mm Nut - Hex Flower - Wrench.stl
24mm Nut - Hex Flower/Files/Preconfigured 3mf/[BBL_P1S] 2x 24mm Nut - Hex Flower + Wrench.3mf
24mm Nut - Hex Flower/Files/STEP/24mm Nut - Hex Flower - Double Threaded.step
24mm Nut - Hex Flower/Files/STEP/24mm Nut - Hex Flower - Single Threaded.step
24mm Nut - Hex Flower/Files/STEP/24mm Nut - Hex Flower - Wrench.step
Metal Hinge Printed Files/Hinge 40-4040CL.stl
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

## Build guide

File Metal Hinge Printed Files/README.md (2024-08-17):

### **Hinge 40-4040CL**  
Replaces default Shick's hinge with an experimental hinge with 3.2mm thickness to support 1/8" metal hinges

Prints standing tall at a slight angle, no supports.  
This angle is intended to provide higher strength where stresses are involved on this hinge.

//TODO: Add model and print images  

### **Hinge Plate Knob M8 For Metal**  
Made for M8 nut.

Print nut face down, supports optional when printing at .2 layer height

**Important:**  
This model uses a 'hack' where I sliced a .05mm wall down the sides of the positioning key which will trick the slicer into generating walls deep within the part leading up to the key - vital for shear strength.  
For printing, make sure you enable "Print Thin Walls" (Cura) (or set "Slice gap closing radius" to 0.0025 if in another slicer) in your slicer to take advantage of this.

//TODO: Add model and print images  

### **Hinge Plate Bushing**  
Made for M8 quick release lever. Supports up to 15mm washer insert.  
Print flat side down

//TODO: Add model and print images

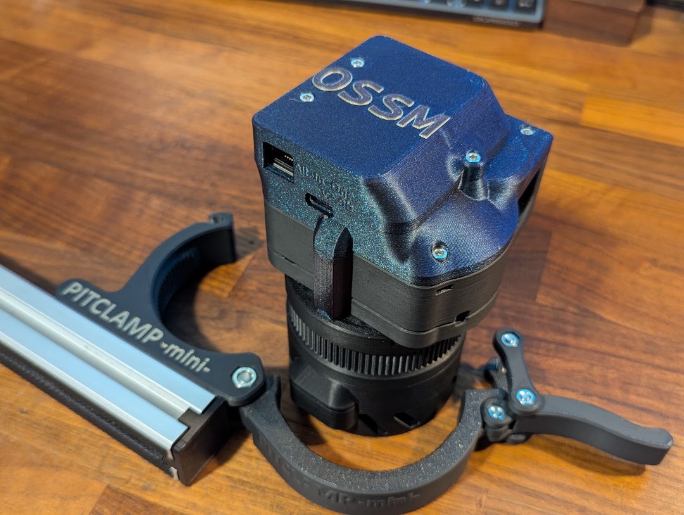
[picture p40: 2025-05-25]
OSSM v2 AIO PCB Backpack Mod/Images/Photos/Assembled.jpg

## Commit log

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2024-08-20 Add Remote Knob files
    [Remote Knob - Knurled With Position Indicator.step, Remote Knob - Knurled With Position Indicator.stl, Remote Knob - Knurled.step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]
2024-08-24 OSSM Remote Model Asset
    [OSSM Remote PCB.step]
2024-09-07 Update speed potentiometer shaft notch height
    [OSSM Remote PCB.step]
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2024-09-08 OSSM - Remote Reimagined v1.0 Release
    [OSSM - Remote Reimagined - Board Interface.step, OSSM - Remote Reimagined - Board Interface.stl, OSSM - Remote Reimagined - Bottom - Ergo.step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]
2024-09-08 Update default print settings for improved supports
    [OSSM - Remote Reimagined.3mf]
2024-09-08 Include Accent Stripe File + Render
    [OSSM - Remote Reimagined - Accent Stripe.step, OSSM - Remote Reimagined - Accent Stripe.stl, OSSM - Remote Reimagined.3mf]
2024-09-09 OSSM branding text template
    [OSSM Logo Template.f3d]
2024-09-09 Increase height of knob pulleys by 1mm to increase reliability
    [OSSM - Remote Reimagined - Speed Knob Helper.step, OSSM - Remote Reimagined - Speed Knob Helper.stl, OSSM - Remote Reimagined - Speed Knob.step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]
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2024-09-11 Add OSSM Default Part STEP
    [Double Double To The Moon 24mm.step]
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2024-09-15 OSSM v2.x AIO Motor Head Mod
    [OSSM - Body - 2.x AIO - Base.step, OSSM - Body - 2.x AIO - Base.stl, OSSM - Body - 2.x AIO - Cover - Default.step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]
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2024-10-22 Add INIU P63-E1 rough model
    [INIU P63-E1 v0.1.step]
2024-10-24 Add INIU P63-E1 BETA model asset
    [INIU P63-E1 BETA.STEP, INIU P63-E1 v0.1.step]
2024-11-13 Add additional clearance to cover
    [OSSM - Body - 2.x AIO - Cover - Extra Clearance.step, OSSM - Body - 2.x AIO - Cover - Extra Clearance.stl, OSSM - Body - 2.x AIO.3mf]
2024-12-20 OSSM v2 AIO PCB Backpack Mod
    [OSSM v2 AIO PCB Backpack - Base.step, OSSM v2 AIO PCB Backpack - Base.stl, OSSM v2 AIO PCB Backpack - Cap (No RJ45).step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]
2024-12-20 Add recess for slight antenna overlap
    [OSSM v2 AIO PCB Backpack - Base.step, OSSM v2 AIO PCB Backpack - Base.stl, OSSM v2 AIO PCB Backpack Mod.3mf]
2024-12-20 Add mounting points for future strain relief add-on
    [OSSM v2 AIO PCB Backpack - Base.step, OSSM v2 AIO PCB Backpack - Base.stl, OSSM v2 AIO PCB Backpack Mod.3mf]
2024-12-20 Move nut inserts up so 20mm threads fully engage from cap
    [OSSM v2 AIO PCB Backpack - Base.step, OSSM v2 AIO PCB Backpack - Base.stl, OSSM v2 AIO PCB Backpack Mod.3mf]
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2024-12-21 Add "Extra Clearance" Cap option
    [OSSM v2 AIO PCB Backpack - Cap - Extra Clearance (No RJ45).step, OSSM v2 AIO PCB Backpack - Cap - Extra Clearance (No RJ45).stl, OSSM v2 AIO PCB Backpack - Cap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]
2024-12-21 New standard cap, v2.01
    [OSSM v2 AIO PCB Backpack - Cap (Default).step, OSSM v2 AIO PCB Backpack - Cap (Default).stl, OSSM v2 AIO PCB Backpack - Cap (No RJ45).step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]
2024-12-21 Cap v2.01 Minor tweak
    [OSSM v2 AIO PCB Backpack - Cap (Default).step, OSSM v2 AIO PCB Backpack - Cap (Default).stl, OSSM v2 AIO PCB Backpack - Cap (No RJ45).step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]
2024-12-21 Add faceplate template and example
    [Keep Calm And OSSM On.step, OSSM v2 AIO PCB Backpack - Faceplate Template.step]
2024-12-23 Strain relief template and 90 degree adapter
    [OSSM v2 AIO PCB Backpack - Strain Relief Template.step, OSSM v2 AIO PCB Backpack - Strain Relief Template.stl, Strain Relief - Adafruit 20v USBC 90 Degree.3mf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]
2025-01-05 Re-export STEP to resolve fusion import issue
    [PitClamp Mini - Motor Cover - 57AIM30 - Ring Interface - Sealed.step]
2025-01-11 Template for creating reference board v2.x negative space
    [OSSM Reference Board v2.x Cutout Template.step]
2025-01-22 (BETA) Smooth PEI plate preconfig for extra smooth surface finish
    [OSSM v2 AIO PCB Backpack Mod (Smooth PEI).3mf]
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2025-01-22 Relocate 3mf and remove reference from readme
    [OSSM - Remote Reimagined.3mf]
2025-02-19 24mm Nut - Hex Flower release
    [24mm Nut - Hex Flower - Double Threaded.step, 24mm Nut - Hex Flower - Double Threaded.stl, 24mm Nut - Hex Flower - Single Threaded.step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]
2025-02-19 Improved first layer settings for smooth PEI and include both cap options
    [OSSM v2 AIO PCB Backpack Mod (Smooth PEI).3mf]
2025-02-19 Include 24mm Nut - Hex Flower - Wrench
    [24mm Nut - Hex Flower - Wrench.step, 24mm Nut - Hex Flower - Wrench.stl]
2025-02-27 Release OSSM Tie Down And Suction Plate 110mm
    [OSSM Tie Down And Suction Plate 110mm (Smooth PEI).3mf, OSSM Tie Down And Suction Plate 110mm.step, OSSM Tie Down And Suction Plate 110mm.stl]
2025-03-05 Settings changes to improve surface finish
    [OSSM v2 AIO PCB Backpack Mod (Smooth PEI).3mf]
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2025-04-13 v2.3 Release - Nut slots improved/widened + Magnet Retention
    [OSSM Mods - AIO PCB Backpack - Base.stp, OSSM Mods - AIO PCB Backpack - Cap (Default).stl, OSSM Mods - AIO PCB Backpack - Cap (Default).stp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]
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2025-06-19 Latest Template - Revised magnet retention (Use glue)
    [AIO PCB Backpack - Faceplate Template.f3d, Faceplate Template.step, Faceplate Template.stl]
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2025-08-20 Shortened default wire cover
    [OSSM Mods - AIO PCB Backpack - Wire Cover (+1mm).stl, OSSM Mods - AIO PCB Backpack - Wire Cover (+1mm).stp, OSSM Mods - AIO PCB Backpack - Wire Cover.stl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]
2025-12-15 Add strain relief file for Meanwell 36v R7BF-P1J
    [OSSM Mods - AIO PCB Backpack - Strain Relief - Meanwell 36v R7BF-P1J.stl, Strain Relief - Meanwell 36v R7BF-P1J.step]
2025-12-29 Remove deprecated OSSM v2.x AIO Motor Head Mod files and documentation
    [OSSM - Body - 2.x AIO - Base.step, OSSM - Body - 2.x AIO - Base.stl, OSSM - Body - 2.x AIO - Cover - Default.step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]
2026-03-11 Added generic usb-c strain relief for backpack mod
    [Strain Relief - USBC 90 Degree - generic.step, Strain Relief - USBC 90 Degree - generic.stl]
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2026-08-29 Fix Print Part kits URL in README
    Updated the Print Part kits link to the new URL.
